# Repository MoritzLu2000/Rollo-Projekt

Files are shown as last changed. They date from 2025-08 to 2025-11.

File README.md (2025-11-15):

# Wireless Rollomodule

In diesem Projekt geht es um die Entwicklung von **kabellosen Rollosteuerungen**, die nur über ein Stromkabel versorgt werden und per **Funkfernbedienung** bedient werden können.  
Jedes Modul basiert auf einem **ESP32** und einem **Schrittmotor**, der das Rollo präzise positioniert.

Der Fokus liegt auf einer einfachen Installation ohne separate Steuerleitungen.  
Die Module können einzeln oder gemeinsam angesteuert werden.  

Später werden in diesem Repository auch die **PCB-Designs** der einzelnen Rollomodule ergänzt.

---

## Aktueller Stand

- Steuerung per Fernbedienung (ESP32 empfängt Funkbefehle)  
- Antrieb über Stepper-Motoren mit Treiberplatine  
- Nur ein Netzkabel pro Rollo nötig  
- Code für mehrere Module vorbereitet  

---

## Geplante Erweiterungen mit Steppermotoren

- Hochladen der PCB-Layouts für jedes Modul  
- Integration einer Positionskalibrierung und einen PID Regler mit einenem magnetic rotary encoder
- Einbindung in Home Assistant
- Optional: WLAN-Steuerung und App-Anbindung  
- Energiesparmodus im Stillstand  

---

## Geplante komplett kabellose Rollomodule – 5-V-Version

Dieses Projekt basiert auf dem gleichen Prinzip wie das ursprüngliche **Wireless-Rollomodule**-Projekt, zielt jedoch auf eine vollständig **kabellose Version** ab.

Jedes Modul nutzt einen **5-V-Schrittmotor** und wird von einem **ESP32** gesteuert.  
Die Energieversorgung erfolgt über einen **Li-Akku**, der über **USB-C** wieder aufgeladen werden kann.  
Damit wird kein festes Stromkabel mehr benötigt. Jedes Rollo arbeitet also autark.

**Eigenschaften der 5-V-Version:**

- 100 % kabelloser Betrieb  
- Kompakte Einheit mit Akku, Ladeelektronik, Motor und Steuerung  
- Aufladung über USB-C  
- Kommunikation per Funkfernbedienung (ESP32-basiert)  
- Gleiche Softwarebasis wie das ursprüngliche, kabelgebundene System

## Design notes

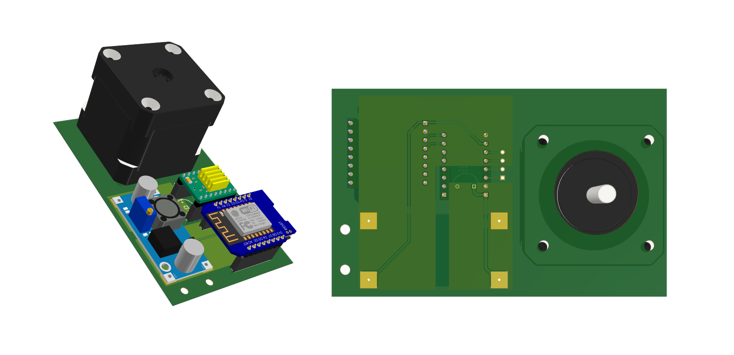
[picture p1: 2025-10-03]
V1/V1.png

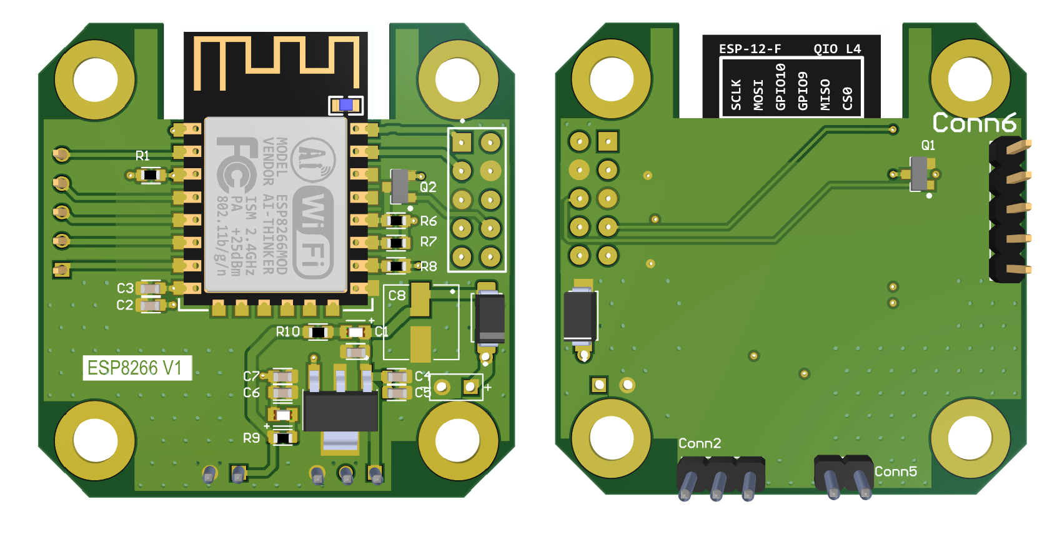
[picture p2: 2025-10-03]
Platine V2/V2.png

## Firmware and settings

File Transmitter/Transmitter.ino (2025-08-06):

#include <Wire.h>
#include <SPI.h>
#include <Adafruit_GFX.h>
#include <Adafruit_SSD1306.h>

#include <esp_now.h>
#include <WiFi.h>

#define SCREEN_WIDTH 128
#define SCREEN_HEIGHT 32
#define OLED_RESET -1
#define SCREEN_ADDRESS 0x3C

const int buttonPin1 = 4;
const int buttonPin2 = 19;
const int buttonPin3 = 23;

int menueState = 0;
int number = 0;

uint8_t broadcastAddress1[] = { 0xEC, 0x64, 0xC9, 0x5D, 0xAD, 0x48 };  // 3 rollo
uint8_t broadcastAddress2[] = { 0xC8, 0x2E, 0x18, 0xC3, 0x99, 0xCC };  // 1 rollo
uint8_t broadcastAddress3[] = { 0xC8, 0x2E, 0x18, 0x14, 0x73, 0xEC };
uint8_t broadcastAddress5[] = { 0xC8, 0x2E, 0x18, 0xC3, 0x80, 0xFC };  // 2 rollo
uint8_t broadcastAddress4[] = { 0xAC, 0x67, 0xB2, 0x09, 0xFF, 0x1C };  // 4 rollo

int devices[5];
int rolloState[5];  // 1 for up, 0 for down

const int ledPin = 2;

typedef struct struct_message {
  int rotations;
  int speed;
  int maxSpeed;
  int acceleration;
  int status;
  int loops;
} struct_message;

struct_message myData;

Adafruit_SSD1306 display(SCREEN_WIDTH, SCREEN_HEIGHT, &Wire, OLED_RESET);
esp_now_peer_info_t peerInfo;

void menueDisplay(String mode, int anzahlmodi);

void OnDataSent(const uint8_t *mac_addr, esp_now_send_status_t status) {
  number++;
  if (number > 5) number = 1;

  char macStr[18];
  snprintf(macStr, sizeof(macStr), "%02X:%02X:%02X:%02X:%02X:%02X",
           mac_addr[0], mac_addr[1], mac_addr[2],
           mac_addr[3], mac_addr[4], mac_addr[5]);

  Serial.print("Receiver ");
  Serial.print(number);
  Serial.print(" send status:\t");

  if (status == ESP_NOW_SEND_SUCCESS) {
    Serial.println("Delivery Success");
    devices[number - 1] = 1;
  } else {
    Serial.println("Delivery Fail");
    devices[number - 1] = 0;
  }
}

void alle(bool direction) {
  myData.rotations = direction ? 20000 : -20000;

  esp_now_send(broadcastAddress1, (uint8_t *)&myData, sizeof(myData));
  esp_now_send(broadcastAddress2, (uint8_t *)&myData, sizeof(myData));
  esp_now_send(broadcastAddress3, (uint8_t *)&myData, sizeof(myData));
  esp_now_send(broadcastAddress4, (uint8_t *)&myData, sizeof(myData));
  esp_now_send(broadcastAddress5, (uint8_t *)&myData, sizeof(myData));
}

void rechts(bool direction) {
  myData.rotations = direction ? 20000 : -20000;

  esp_now_send(broadcastAddress2, (uint8_t *)&myData, sizeof(myData));
  esp_now_send(broadcastAddress4, (uint8_t *)&myData, sizeof(myData));
}

void front(bool direction) {
  myData.rotations = direction ? 20000 : -20000;

  esp_now_send(broadcastAddress1, (uint8_t *)&myData, sizeof(myData));
  esp_now_send(broadcastAddress5, (uint8_t *)&myData, sizeof(myData));
}

void setup() {
  Serial.begin(115200);

  WiFi.mode(WIFI_STA);

  if (!display.begin(SSD1306_SWITCHCAPVCC, SCREEN_ADDRESS)) {
    Serial.println(F("SSD1306 allocation failed"));
    while (true);
  }

  display.clearDisplay();
  display.display();

  if (esp_now_init() != ESP_OK) {
    Serial.println("Error initializing ESP-NOW");
    return;
  }

  esp_now_register_send_cb(OnDataSent);

  peerInfo.channel = 0;
  peerInfo.encrypt = false;

  // Peers hinzufügen
  memcpy(peerInfo.peer_addr, broadcastAddress1, 6);
  esp_now_add_peer(&peerInfo);
  memcpy(peerInfo.peer_addr, broadcastAddress2, 6);
  esp_now_add_peer(&peerInfo);
  memcpy(peerInfo.peer_addr, broadcastAddress3, 6);
  esp_now_add_peer(&peerInfo);
  memcpy(peerInfo.peer_addr, broadcastAddress4, 6);
  esp_now_add_peer(&peerInfo);
  memcpy(peerInfo.peer_addr, broadcastAddress5, 6);
  esp_now_add_peer(&peerInfo);

  pinMode(ledPin, OUTPUT);
  pinMode(buttonPin1, INPUT_PULLDOWN);
  pinMode(buttonPin2, INPUT_PULLDOWN);
  pinMode(buttonPin3, INPUT_PULLDOWN);
}

void loop() {
  myData.speed = 300;
  myData.maxSpeed = 500;
  myData.acceleration = 300;
  myData.status = 1;
  myData.loops = 4;

  if (digitalRead(buttonPin1)) {
    menueState++;
    if (menueState == 3) menueState = 0;
  }

  switch (menueState) {
    case 0: menueDisplay("alle Rollos", 3); break;
    case 1: menueDisplay("front", 3); break;
    case 2: menueDisplay("rechts", 3); break;
  }

  if (digitalRead(buttonPin3)) {
    if (menueState == 0) alle(true);
    if (menueState == 1) front(true);
    if (menueState == 2) rechts(true);
  }

  if (digitalRead(buttonPin2)) {
    if (menueState == 0) alle(false);
    if (menueState == 1) front(false);
    if (menueState == 2) rechts(false);
  }

  delay(200);
}

void menueDisplay(String mode, int anzahlmodi) {
  display.clearDisplay();
  display.setTextSize(1);
  display.setTextColor(SSD1306_WHITE);
  display.setCursor(0, 0);
  display.print(mode);

  int deltax = 128 / anzahlmodi;
  int x1 = deltax * menueState;
  int x2 = deltax * (menueState + 1);
  display.drawLine(x1, 25, x2, 25, WHITE);
  display.display();
}

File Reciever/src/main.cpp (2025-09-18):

#include <Arduino.h>
#include <WiFi.h>
#include <esp_now.h>

#define STEP_PIN    17
#define DIR_PIN     16
#define ENABLE_PIN  21
#define LED_PIN     2

bool state = false;

// Globale Variablen für Step-Zähler
volatile int stepsDone = 0;
volatile int stepsTarget = 0;

// Zeiger zum Hardware-Timer
hw_timer_t* periodicTimer = nullptr;

// Prototypes
void IRAM_ATTR onISR();
void startPeriodicUs(uint32_t us);
void stopPeriodic();
void destroyTimer();
void OnDataRecv(const uint8_t* mac, const uint8_t* incomingData, int len);

struct struct_message {
  int rotations, speed, maxSpeed, acceleration, status, loops;
};
struct_message myData;

// === ISR ===
void IRAM_ATTR onISR() { 
  if (state) {
    digitalWrite(STEP_PIN, HIGH);  
    state = false;
  } else {
    digitalWrite(STEP_PIN, LOW);   
    state = true;
  }

  stepsDone++;
  if (stepsDone >= stepsTarget) {
    stopPeriodic();
    stepsDone = 0;
  }
}

void startPeriodicUs(uint32_t us) {
  if (periodicTimer == nullptr) {
    periodicTimer = timerBegin(1, 80, true);   // Timer 1, 1 µs Takt
    timerAttachInterrupt(periodicTimer, &onISR, true);
  }
  timerWrite(periodicTimer, 0);
  timerAlarmWrite(periodicTimer, us, true);    // auto-reload
  timerAlarmEnable(periodicTimer);
}

void stopPeriodic() {
  if (periodicTimer) timerAlarmDisable(periodicTimer);
}

void destroyTimer() {
  if (periodicTimer) {
    timerEnd(periodicTimer);
    periodicTimer = nullptr;
  }
}

void OnDataRecv(const uint8_t* mac, const uint8_t* incomingData, int len) {
  memcpy(&myData, incomingData, sizeof(myData));
  digitalWrite(ENABLE_PIN, LOW);
  digitalWrite(LED_PIN, HIGH);

  stepsTarget = myData.rotations * 15;
  stepsDone = 0;

  // Richtung einstellen
  if (stepsTarget > 0) {
    digitalWrite(DIR_PIN, HIGH);
  } else {
    digitalWrite(DIR_PIN, LOW);
    stepsTarget = -stepsTarget;
  }

  // Timer starten
  startPeriodicUs(85);
  digitalWrite(LED_PIN, LOW);
}

void setup() {
  Serial.begin(9600);
  pinMode(STEP_PIN, OUTPUT);
  pinMode(DIR_PIN, OUTPUT);
  pinMode(ENABLE_PIN, OUTPUT);
  pinMode(LED_PIN, OUTPUT);

  WiFi.mode(WIFI_STA);
  if (esp_now_init() != ESP_OK) {
    Serial.println("ESP-NOW init error");
    return;
  }
  esp_now_register_recv_cb(OnDataRecv);
}

void loop() {}

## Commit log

2025-08-06 Update Transmitter.ino
    problems with librarys now esp32 lib 2.0.24
    [Transmitter.ino]
2025-09-18 stepper mit timer gesteuert
2025-09-18 stepper mit timer gesteuert edit
2025-10-03 Upload V1 pcb
    [PCB1.GBL, PCB1.GBO, PCB1.GBP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]
2025-11-09 Initialize README with project details
    Added project description and current status for wireless rollomodule development.
2025-11-15 Update README with wireless module plans
    Added details about planned wireless roller modules with a 5V motor and ESP32 control.
